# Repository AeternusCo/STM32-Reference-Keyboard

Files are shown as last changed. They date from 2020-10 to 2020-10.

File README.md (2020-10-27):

# STM32 Keyboard Reference Project

## WARNING

This schematic has not been officially tested. It follows best practices and should work, but please confirm your design before placing a large order!

PCBs have been ordered to confirm the design works as intended, this warning will be removed once the design is verified.

## Goals

The primary goal of this project is to provide a semi-opinionated starting point for people new to STM32 microcontrollers.
A majority of commonly used keyboard features are broken out on pins that are best suited for the purpose. (RGB on SPI, split on USART, etc)

A secondary goal of this project is to provide a schematic that allows for swapping between a number of readily available STM32 MCUs based on need and availability.

An example BOM is listed below, while a majority of parts are JLCPCB basic parts, the goal of this project is not to provide a _cheap_ project, but a common project.

Components used are 0603 or larger as to make hand solderability as easy as possible for the designer.

## Libraries Used

The following non-standard libraries were used to design this project:

- [ai03-2725/Type-C.pretty](https://github.com/ai03-2725/Type-C.pretty)
- [ai03-2725/MX_Alps_Hybrid/MXOnly.pretty](https://github.com/ai03-2725/MX_Alps_Hybrid)

It is recommended to include these as global libraries in KiCAD, as they are very commonly used on most keyboard projects.

## Pictures

### Schematic

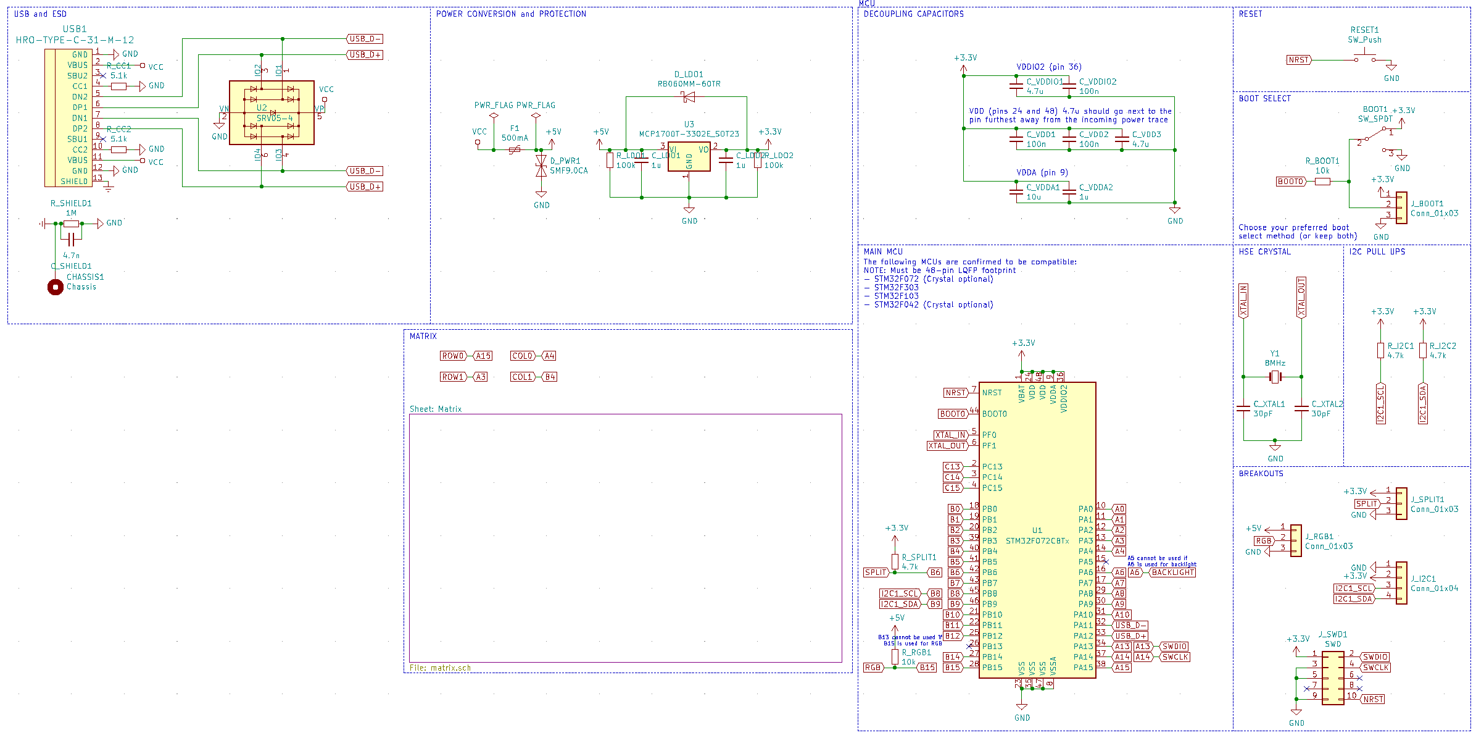
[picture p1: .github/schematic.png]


### PCB

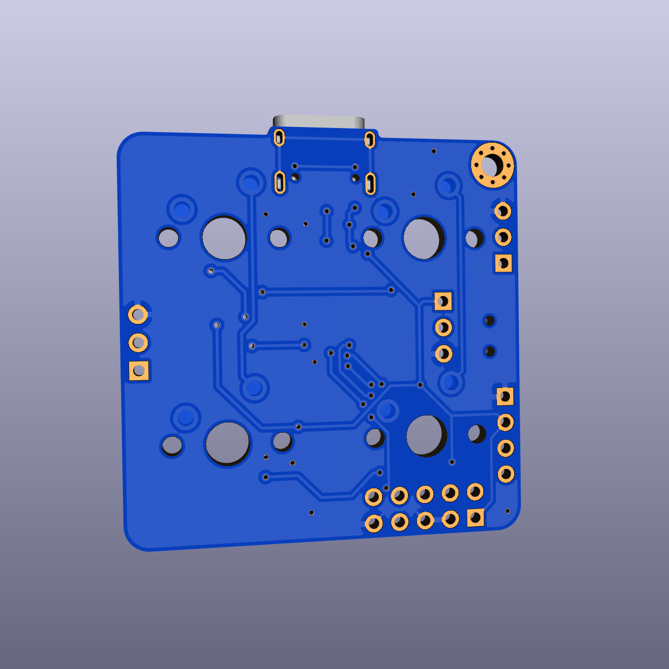
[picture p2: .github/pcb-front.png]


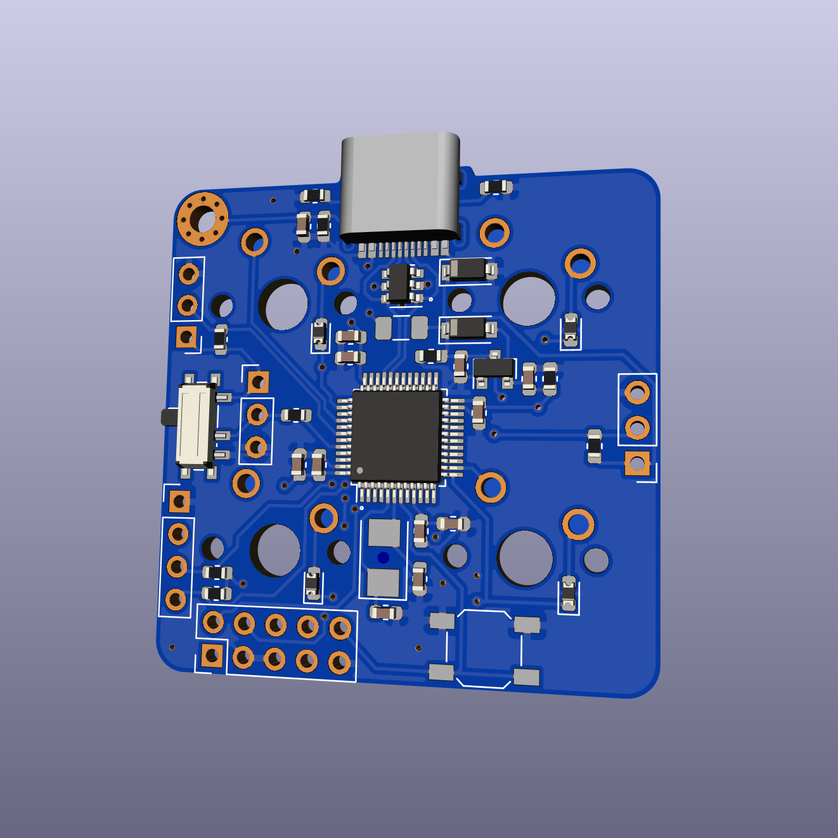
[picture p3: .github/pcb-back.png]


## BOM

| Designator | Description | Package | LCSC Part Number |
|---|---| ---|---|
|Y1|8MHz|SMD-5032_2P|C115962|
|USB1|HRO-TYPE-C-31-M-12|HRO-TYPE-C-31-M-12|C165948|
|U1|STM32F072CBTx|LQFP-48_7x7mm_P0.5mm|C81720|
|U2|SRV05-4|SOT-23-6|C85364|
|U3|MCP1700T-3302E_SOT23|SOT-23|C39051|
|RESET1|SW_Push|SMD-SW-4_5.1x5.1x1.5|C318884|
|R_SHIELD1|1M|0603|C22935|
|R_RGB1,R_BOOT1|10k|0603|C25804|
|R_LDO2,R_LDO1|100k|0603|C25803|
|R_I2C2,R_I2C1|4.7k|0603|C23162|
|R_CC2,R_CC1|5.1k|0603|C23186|
|R_USB1|1.5k|0603|C328342|
|F1|500mA|1206|C151162|
|D_PWR1|SMF9.0CA|SOD-123|C123799|
|D_LDO1|RB060MM-60TR|SOD-123|C115330|
|D4,D3,D2,D1|CD4148W|0603|C109002|
|C_XTAL2,C_XTAL1|30pF|0603|C22397|
|C_VDDIO2,C_VDD2,C_VDD1|100n|0603|C14663|
|C_VDDIO1,C_VDD3|4.7u|0603|C19666|
|C_VDDA2,C_LDO2,C_LDO1|1u|0603|C15849|
|C_VDDA1|10u|0603|C19702|
|C_SHIELD1|4.7n|0603|C53987|
|BOOT1|SW_SPDT|SW_SPDT_PCM12|C221841|

## License

This project is licensed under the Unlicense. Please see [LICENSE](LICENSE) for more information.

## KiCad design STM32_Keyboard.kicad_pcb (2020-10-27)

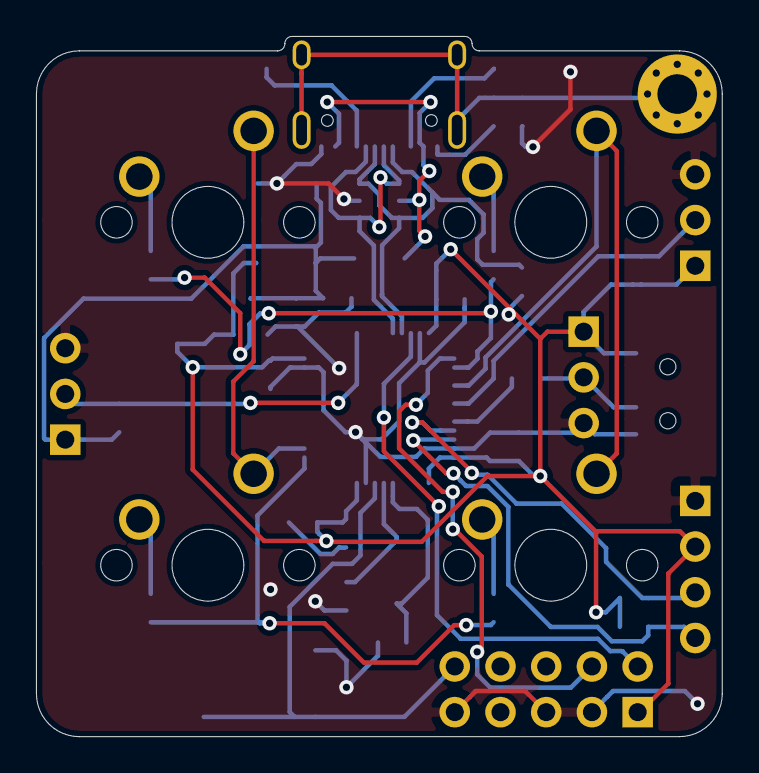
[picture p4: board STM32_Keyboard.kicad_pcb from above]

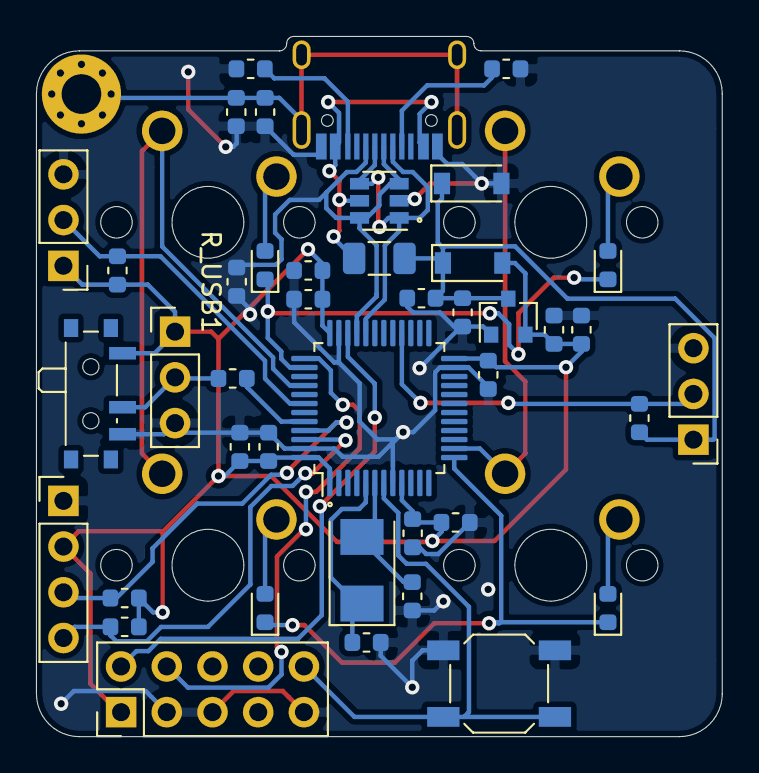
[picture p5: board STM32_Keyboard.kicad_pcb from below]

Board: 2 copper layers, 38.1 x 38.9 mm, 47 parts (43 on the bottom side), 28 nets.

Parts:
BOOT1: SW_SPDT; SW_SPDT_PCM12
CHASSIS1: Chassis; MountingHole_2.2mm_M2_Pad_Via
C_LDO1, C_LDO2: 1u; C_0603_1608Metric
C_SHIELD1: 4.7n; C_0603_1608Metric
C_VDD1, C_VDD2: 100n; C_0603_1608Metric
C_VDD3: 4.7u; C_0603_1608Metric
C_VDDA1: 10u; C_0603_1608Metric
C_VDDA2: 1u; C_0603_1608Metric
C_VDDIO1: 4.7u; C_0603_1608Metric
C_VDDIO2: 100n; C_0603_1608Metric
C_XTAL1, C_XTAL2: 30pF; C_0603_1608Metric
D1, D2, D3, D4: CD4148W; D_0603_1608Metric
D_LDO1: RB060MM-60TR; D_SOD-123
D_PWR1: SMF9.0CA; D_SOD-123
F1: 500mA; Fuse_1206_3216Metric
J_BOOT1: Conn_01x03; PinHeader_1x03_P2.54mm_Vertical
J_I2C1: Conn_01x04; PinHeader_1x04_P2.54mm_Vertical
J_RGB1: Conn_01x03; PinHeader_1x03_P2.54mm_Vertical
J_SPLIT1: Conn_01x03; PinHeader_1x03_P2.54mm_Vertical
J_SWD1: SWD; PinHeader_2x05_P2.54mm_Vertical
RESET1: SW_Push; SW_SPST_SKQG_WithStem
R_BOOT1: 10k; R_0603_1608Metric
R_CC1, R_CC2: 5.1k; R_0603_1608Metric
R_I2C1, R_I2C2: 4.7k; R_0603_1608Metric
R_LDO1, R_LDO2: 100k; R_0603_1608Metric
R_RGB1: 10k; R_0603_1608Metric
R_SHIELD1: 1M; R_0603_1608Metric
R_SPLIT1: 4.7k; R_0603_1608Metric
R_USB1: 1.5k; R_0603_1608Metric
SW1, SW2, SW3, SW4: SW_Push; MXOnly-1U-NoLED
U1: STM32F072CBTx; LQFP-48_7x7mm_P0.5mm
U2: SRV05-4; SOT-23-6
U3: MCP1700T-3302E_SOT23; SOT-23
USB1: HRO-TYPE-C-31-M-12
Y1: 8MHz; Crystal_SMD_5032-2Pin_5.0x3.2mm

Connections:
+3V3: BOOT1.1, C_LDO2.1, C_VDD1.1, C_VDD2.1, C_VDD3.1, C_VDDA1.1, C_VDDA2.1, C_VDDIO1.1, C_VDDIO2.1, D_LDO1.2, J_BOOT1.1, J_I2C1.2, J_SPLIT1.1, J_SWD1.1, R_I2C1.1, R_I2C2.1, R_LDO2.1, R_SPLIT1.1, R_USB1.1, U1.1, U1.9, U1.24, U1.36, U1.48, U3.2
+5V: C_LDO1.1, D_LDO1.1, D_PWR1.1, F1.1, J_RGB1.1, R_LDO1.1, R_RGB1.1, U3.3
A3: D3.1, D4.1, U1.13
A4: SW1.2, SW3.2, U1.14
A13: J_SWD1.2, U1.34
A14: J_SWD1.4, U1.37
A15: D1.1, D2.1, U1.38
B4: SW2.2, SW4.2, U1.40
B6: J_SPLIT1.2, R_SPLIT1.2, U1.42
B8: J_I2C1.3, R_I2C1.2, U1.45
B9: J_I2C1.4, R_I2C2.2, U1.46
B15: J_RGB1.2, R_RGB1.2, U1.28
BOOT0: R_BOOT1.2, U1.44
Earth: CHASSIS1.1, C_SHIELD1.2, R_SHIELD1.2, USB1.13
GND: BOOT1.3, C_LDO1.2, C_LDO2.2, C_SHIELD1.1, C_VDD1.2, C_VDD2.2, C_VDD3.2, C_VDDA1.2, C_VDDA2.2, C_VDDIO1.2, C_VDDIO2.2, C_XTAL1.2, C_XTAL2.2, D_PWR1.2, J_BOOT1.3, J_I2C1.1, J_RGB1.3, J_SPLIT1.3, J_SWD1.3, J_SWD1.5, J_SWD1.9, RESET1.2, R_CC1.1, R_CC2.1, R_LDO1.2, R_LDO2.2, R_SHIELD1.1, U1.8, U1.23, U1.35, U1.47, U2.2, U3.1, USB1.1, USB1.12
NRST: J_SWD1.10, RESET1.1, U1.7
unnamed: BOOT1.2, J_BOOT1.2, R_BOOT1.1
unnamed: D1.2, SW1.1
unnamed: D2.2, SW2.1
unnamed: D3.2, SW3.1
unnamed: D4.2, SW4.1
unnamed: R_CC1.2, USB1.4
unnamed: R_CC2.2, USB1.10
USB_D+: R_USB1.2, U1.33, U2.3, U2.6, USB1.6, USB1.8
USB_D-: U1.32, U2.1, U2.4, USB1.5, USB1.7
VCC: F1.2, U2.5, USB1.2, USB1.11
XTAL_IN: C_XTAL1.1, U1.5, Y1.1
XTAL_OUT: C_XTAL2.1, U1.6, Y1.2

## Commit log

2020-10-23 Initial commit.
    [STM32_Keyboard-B_Cu.gbr, STM32_Keyboard-B_Mask.gbr, STM32_Keyboard-B_Paste.gbr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]
2020-10-23 Added schematic screenshot.
2020-10-23 Formatted BOM.
2020-10-23 Added reference BOM.
2020-10-23 Fixed formatting issues in BOM.
2020-10-23 Reorganized BOM.
2020-10-23 Removed 3d model reference.
    [STM32_Keyboard.kicad_pcb]
2020-10-27 Added 1.5kΩ USB D+ pull up resistor.
    [STM32_Keyboard.kicad_pcb, STM32_Keyboard.sch]
